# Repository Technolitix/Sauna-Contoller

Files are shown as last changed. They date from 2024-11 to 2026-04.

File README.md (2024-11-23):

# Sauna Controller

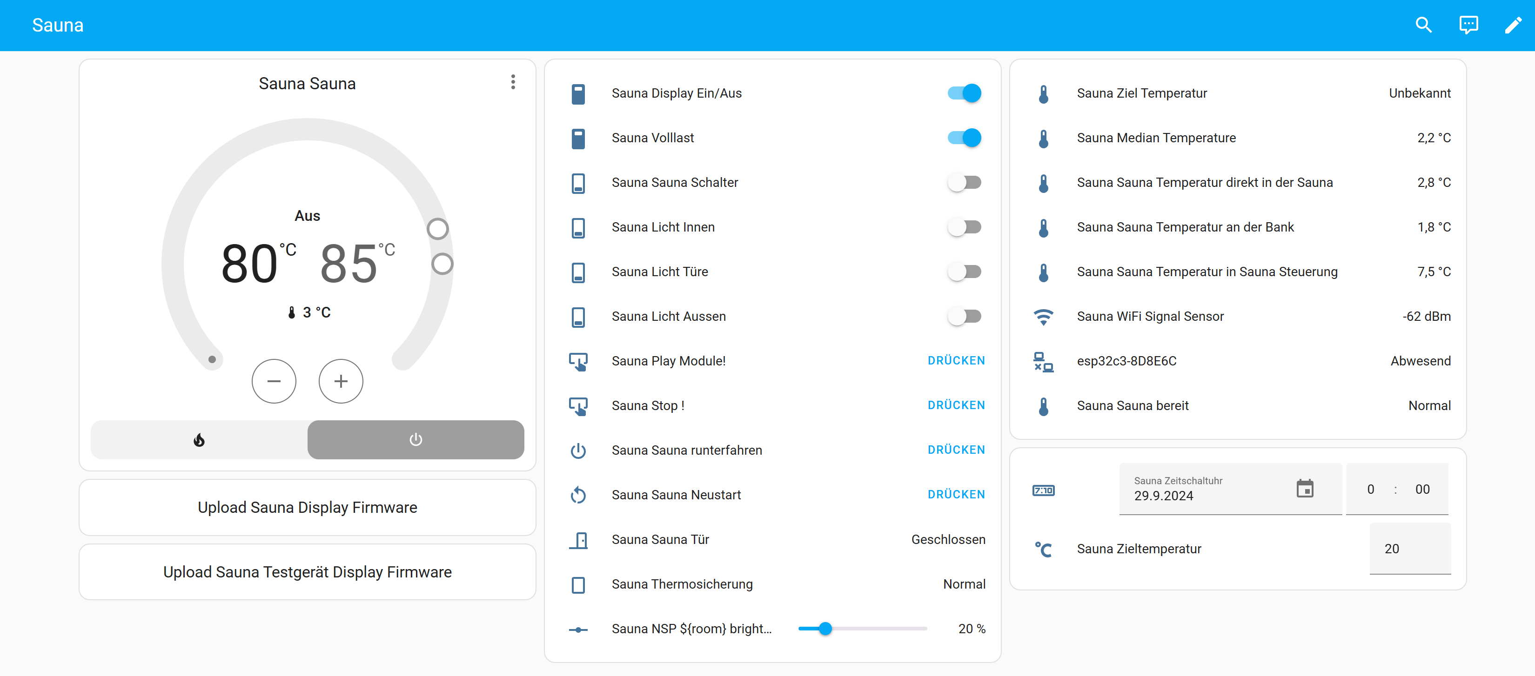
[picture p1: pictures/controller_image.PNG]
Sauna Controller


A project for controlling a sauna using sensors and actuators. This application allows precise management of temperature, humidity, and other parameters to ensure an optimal sauna experience.

---

## Features

- **Temperature Control**: Automatically adjusts the temperature based on predefined settings.
- **Humidity Management**: Integrates humidity sensors for maintaining the perfect sauna environment.
- **Scheduling**: Enables the sauna to operate at predefined times.
- **Fallback Mode**: Ensures stable operation even during connectivity issues.

---

## Configuration Overview

The main configuration file is `sauna1.yaml`. It contains all the necessary settings for operating the sauna controller. Sensitive data such as passwords and API keys are managed through references (`!secret`) in a separate file, such as `secrets.yaml`.

Example of a reference in the YAML file:
```yaml
wifi:
  ssid: !secret wifi_ssid_sauna
  password: !secret wifi_password_sauna
```

### Note
The `secrets.yaml` file is not included in this repository. It should contain sensitive data and remain private.

---

## Directory Structure

- **`config/`**: Contains main configuration files like `sauna1.yaml`.
- **`pictures/`**: Contains images for documentation and illustration.
- **`scripts/`**: Scripts supporting sauna control.
- **`logs/`**: Log files for debugging and tracking.

---

## Installation and Usage

### Prerequisites

- A device capable of managing the controller (e.g., Raspberry Pi, ESP32).
- Sensors and actuators compatible with the sauna setup.

### Steps

1. **Clone the repository**:
   ```bash
   git clone https://github.com/Technolitix/Sauna-Controller.git
   ```
2. **Adjust the configuration file**:
   Edit `sauna1.yaml` to suit your sauna's specific requirements.
3. **Configure secrets**:
   Create a `secrets.yaml` file and add sensitive data:
   ```yaml
   wifi_ssid_sauna: "YourWiFiName"
   wifi_password_sauna: "YourWiFiPassword"
   ```
4. **Deploy and start**:
   Upload the configuration to your device and start the controller.

---

## Security

- The `secrets.yaml` file should never be included in the repository.
- Always ensure sensitive data is stored externally and securely.

---

## Contact

If you have any questions or issues, feel free to open an [Issue](https://github.com/Technolitix/Sauna-Controller/issues).

---

## License

This project is licensed under the [MIT License](LICENSE).

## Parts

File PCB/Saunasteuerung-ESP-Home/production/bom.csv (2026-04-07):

Designator | Footprint | Quantity | Value | LCSC Part #
A1 | ESP32-S3-ETH | 1 | ESP32-S3-ETH
C1 | CP_Elec_6.3x3.9 | 1 | 220uF
C3 | 0603 | 1 | 1uF
D1, D10, D4, D6, D8 | D_SOD-123 | 5 | 1N4148W
D11, D12, D13, D14, D15, D2, D3, D5, D7, D9 | 0603 | 10 | LED
IC1 | SO08-SKINNYPADS | 1 | WS2811
J1, J2, J3 | HB9500M956P | 3 | HB9500M-9.5-6P
J4 | JST_XH_B8B-XH-A_1x08_P2.50mm_Vertical | 1 | Frontpanel I/O
J6 | JST_XH_B5B-XH-A_1x05_P2.50mm_Vertical | 1 | Frontpanel I2C
J7 | JST_XH_B3B-XH-A_1x03_P2.50mm_Vertical | 1 | WS2812
J8 | 696106003002_696106003002 | 1 | 696106003002
K1, K2, K3 | Relay_SPDT_RAYEX-L90 | 3 | RAYEX-L90
K4, K5 | Relay_SPDT_Omron_G2RL-1-E | 2 | G2RL-1-E
LS1 | CEM-1205C_CUI_CEM-1205C | 1 | CEM-1205C
PS1 | HLK-10M05_CONV_HLK-10M05 | 1 | HLK-10M05
Q1, Q2, Q3, Q5, Q6 | SOT-23 | 5 | S8550
Q10 | SOT-23 | 1 | 2N7002
Q11, Q12, Q8 | TO-252-2 | 3 | NTD5867NL
Q4, Q7, Q9 | SOT-323_SC-70 | 3 | BSS214NW
R1, R10, R12, R16, R19, R20, R23, R25, R27, R28, R30, R31, R33, R35, R37, R4, R6, R8 | 0603 | 18 | 1k
R11, R17, R2, R24, R26, R29, R32, R34, R36, R38, R39, R40, R7 | 0603 | 13 | 10k
R13, R14, R3, R5, R9 | 0603 | 5 | 2.2k
R15 | 0603 | 1 | 4.7k
R18 | 0603 | 1 | 2k74
R21, R41, R42 | 0603 | 3 | 33
R22 | 0603 | 1 | 100
RV1 | RV_Disc_D7mm_W3.4mm_P5mm | 1 | 10D561K
U1, U10, U2, U3, U9 | SOP-4_4.4x2.6mm_P1.27mm | 5 | FODM217A
U5 | TO-92L | 1 | DS18B20
X1 | 250-212_P-250-212 | 1 | Sensors
X2 | 250-212_P-250-212 | 1 | LED's

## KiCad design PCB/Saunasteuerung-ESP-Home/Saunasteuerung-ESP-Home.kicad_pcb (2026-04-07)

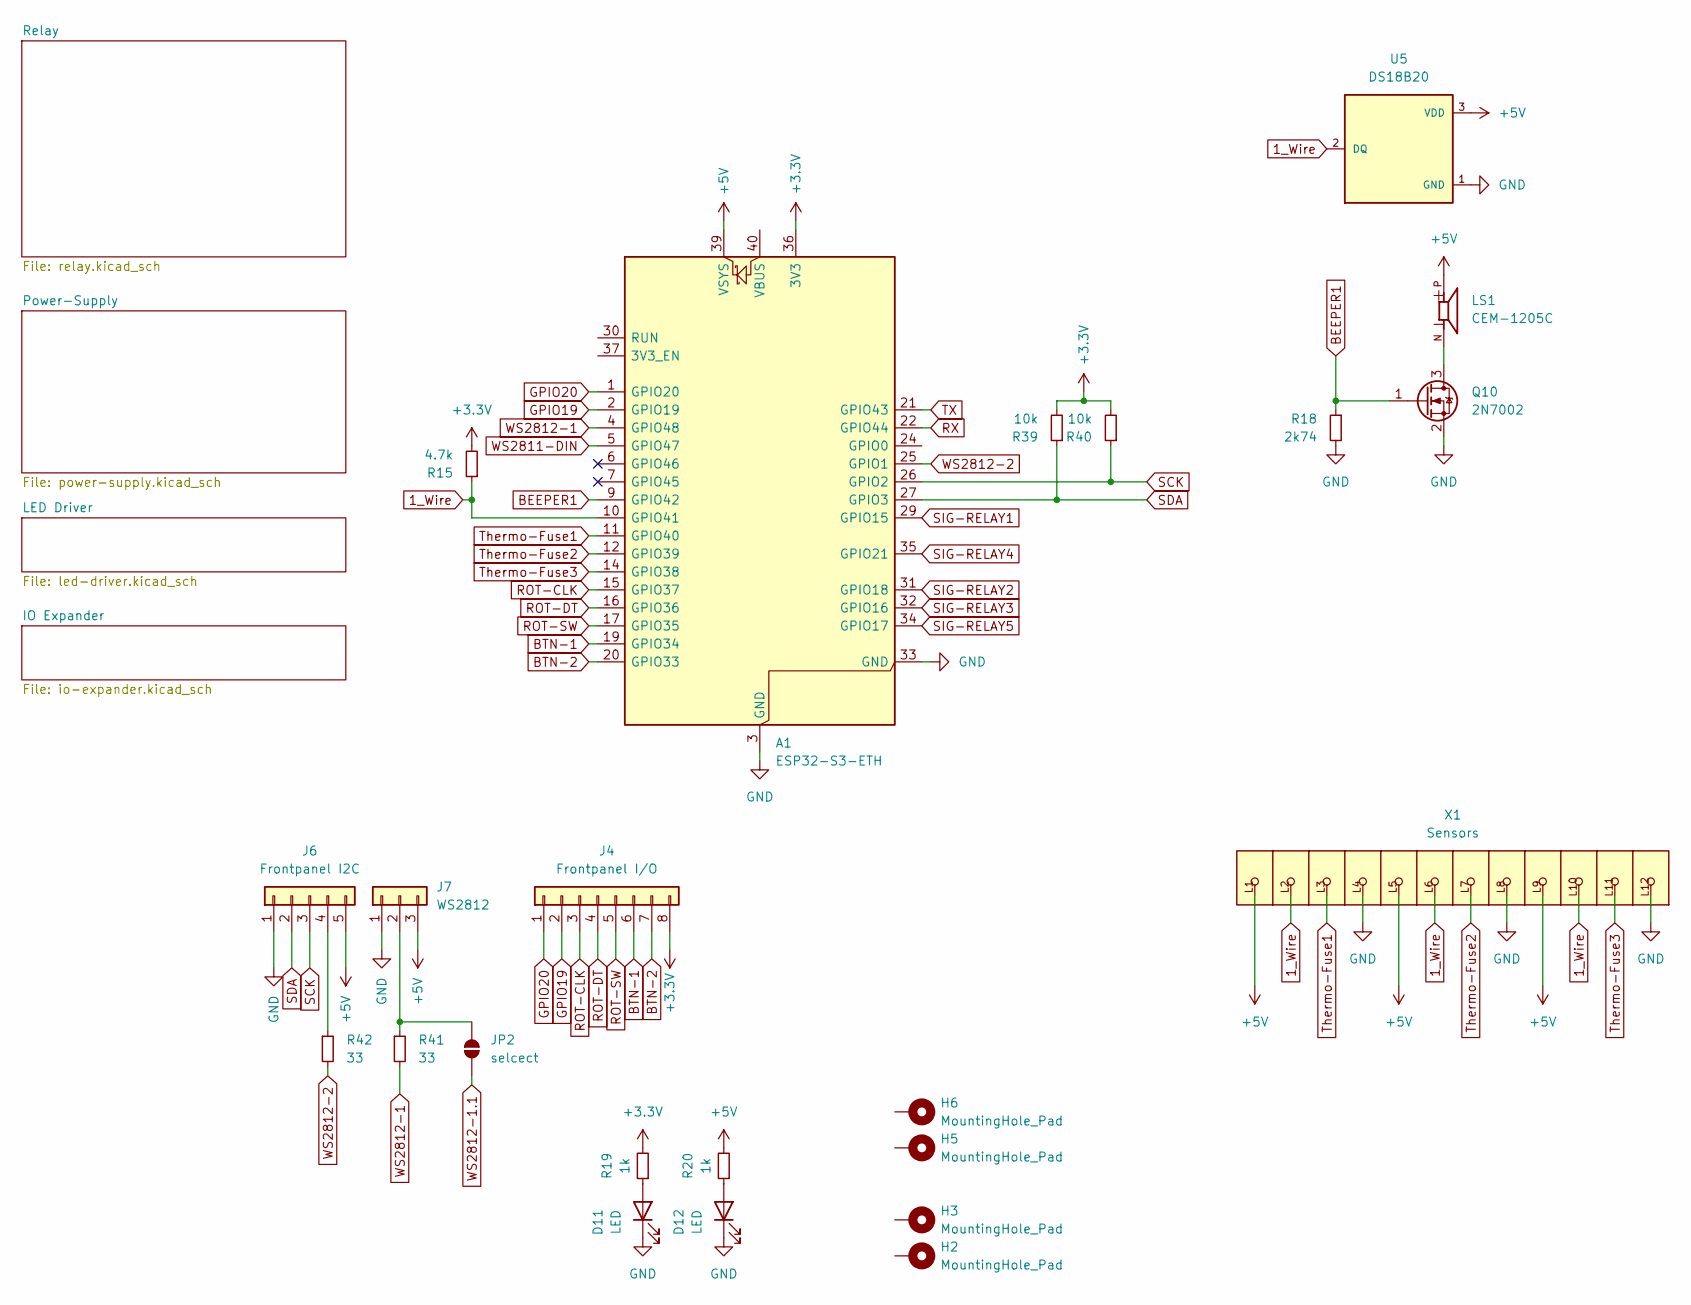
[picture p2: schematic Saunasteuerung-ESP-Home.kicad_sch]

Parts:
A1: ESP32-S3-ETH
D11, D12: LED; LED_0603_1608Metric
H2, H3, H5, H6: MountingHole_Pad; MountingHole_3.2mm_M3_DIN965_Pad_TopBottom
J4: Frontpanel I/O; JST_XH_B8B-XH-A_1x08_P2.50mm_Vertical
J6: Frontpanel I2C; JST_XH_B5B-XH-A_1x05_P2.50mm_Vertical
J7: WS2812; JST_XH_B3B-XH-A_1x03_P2.50mm_Vertical
JP2: selcect; SolderJumper-2_P1.3mm_Open_TrianglePad1.0x1.5mm
LS1: CEM-1205C; CEM-1205C_CUI_CEM-1205C
Q10: 2N7002; SOT-23
R15: 4.7k; R_0603_1608Metric
R18: 2k74; R_0603_1608Metric
R19, R20: 1k; R_0603_1608Metric
R39, R40: 10k; R_0603_1608Metric
R41, R42: 33; R_0603_1608Metric
U5: DS18B20; TO-92L; PARTREV 5
X1: Sensors; 250-212_P-250-212

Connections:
1_Wire: A1.10 (GPIO41), R15.1, U5.2 (DQ), X1.L2, X1.L6, X1.L10
+3.3V: A1.36 (3V3), J4.8, R15.2, R19.2, R39.2, R40.2
+5V: A1.39 (VSYS), J6.5, J7.3, LS1.P, R20.2, U5.3 (VDD), X1.L1, X1.L5, X1.L9; also elsewhere on the board
BEEPER1: A1.9 (GPIO42), Q10.1 (G), R18.1
BTN-1: A1.19 (GPIO34), J4.6
BTN-2: A1.20 (GPIO33), J4.7
GND: A1.3 (GND), A1.8 (GND), A1.13 (GND), A1.18 (GND), A1.23 (GND), A1.28 (GND), A1.33 (GND), A1.38 (GND), D11.1 (K), D12.1 (K), J6.1, J7.1, Q10.2 (S), R18.2, U5.1 (GND), X1.L4, X1.L8, X1.L12; also elsewhere on the board
GPIO19: A1.2 (GPIO19), J4.2
GPIO20: A1.1 (GPIO20), J4.1
unnamed: D11.2 (A), R19.1
unnamed: D12.2 (A), R20.1
unnamed: J6.4, R42.1
unnamed: J7.2, JP2.2 (B), R41.1
unnamed: LS1.N, Q10.3 (D)
ROT-CLK: A1.15 (GPIO37), J4.3
ROT-DT: A1.16 (GPIO36), J4.4
ROT-SW: A1.17 (GPIO35), J4.5
RX: A1.22 (GPIO44)
SCK: A1.26 (GPIO2), J6.3, R40.1
SDA: A1.27 (GPIO3), J6.2, R39.1
SIG-RELAY1: A1.29 (GPIO15); also elsewhere on the board
SIG-RELAY2: A1.31 (GPIO18); also elsewhere on the board
SIG-RELAY3: A1.32 (GPIO16); also elsewhere on the board
SIG-RELAY4: A1.35 (GPIO21); also elsewhere on the board
SIG-RELAY5: A1.34 (GPIO17); also elsewhere on the board
TX: A1.21 (GPIO43)
Thermo-Fuse1: A1.11 (GPIO40), X1.L3
Thermo-Fuse2: A1.12 (GPIO39), X1.L7
Thermo-Fuse3: A1.14 (GPIO38), X1.L11
WS2811-DIN: A1.5 (GPIO47); also elsewhere on the board
WS2812-1: A1.4 (GPIO48), R41.2
WS2812-1.1: JP2.1 (A); also elsewhere on the board
WS2812-2: A1.25 (GPIO1), R42.2

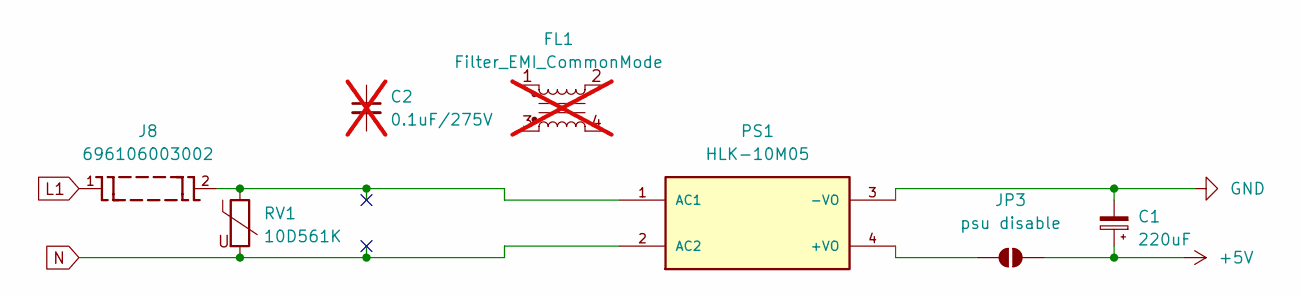
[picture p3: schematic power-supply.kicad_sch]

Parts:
C1: 220uF; CP_Elec_6.3x3.9
C2: 0.1uF/275V; not fitted
FL1: Filter_EMI_CommonMode; L_CommonMode_PulseElectronics_PH9455x105NL_1; not fitted
J8: 696106003002; 696106003002_696106003002; PART-NUMBER 696106003002
JP3: psu disable; SolderJumper-2_P1.3mm_Bridged_Pad1.0x1.5mm
PS1: HLK-10M05; HLK-10M05_CONV_HLK-10M05; PARTREV V1.8
RV1: 10D561K; RV_Disc_D7mm_W3.4mm_P5mm

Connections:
+5V: C1.1, JP3.2 (B); also elsewhere on the board
GND: C1.2, PS1.3 (-VO); also elsewhere on the board
L1: J8.1; also elsewhere on the board
N: PS1.2 (AC2), RV1.2; also elsewhere on the board
unnamed: JP3.1 (A), PS1.4 (+VO)

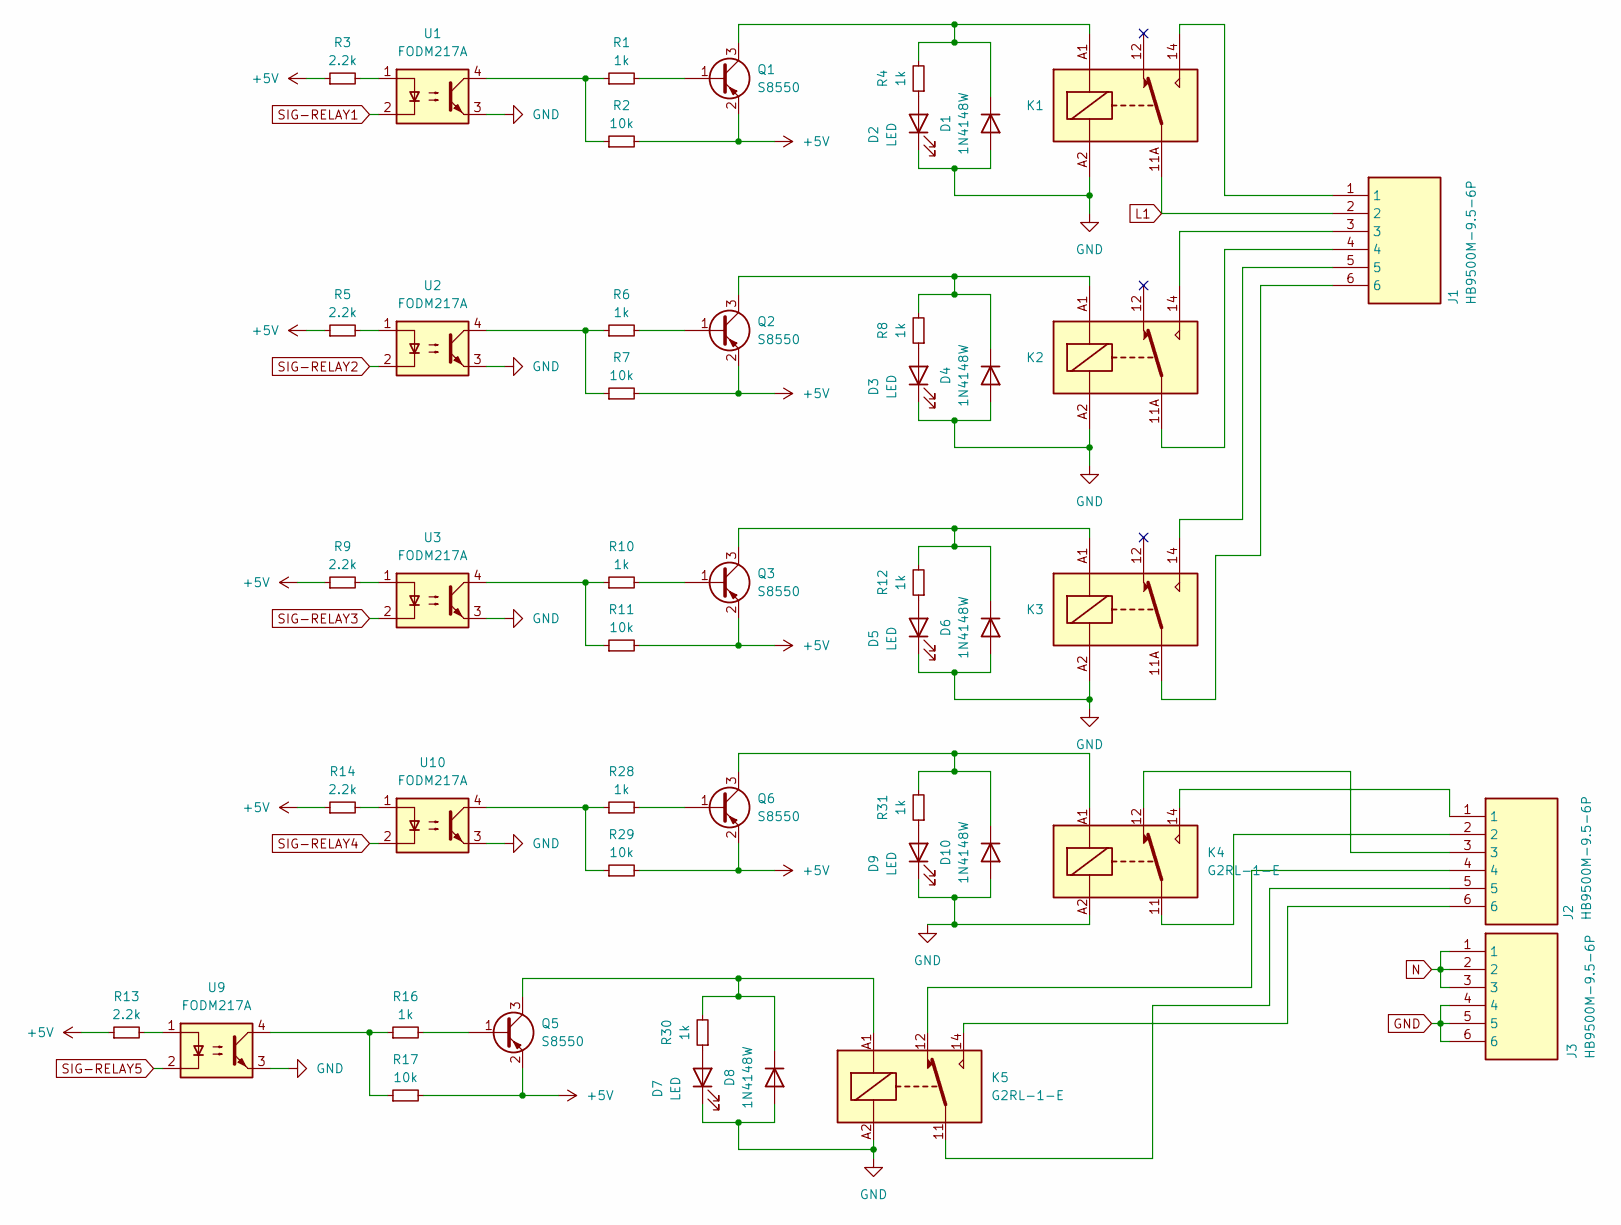
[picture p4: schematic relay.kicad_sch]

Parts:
D1, D4, D6, D8, D10: 1N4148W; D_SOD-123
D2, D3, D5, D7, D9: LED; LED_0603_1608Metric
J1, J2, J3: HB9500M-9.5-6P; HB9500M956P; Manufacturer_Part_Number HB9500M-9.5-6P
K1, K2, K3: RAYEX-L90; Relay_SPDT_RAYEX-L90
K4, K5: G2RL-1-E; Relay_SPDT_Omron_G2RL-1-E
Q1, Q2, Q3, Q5, Q6: S8550; SOT-23
R1, R4, R6, R8, R10, R12, R16, R28, R30, R31: 1k; R_0603_1608Metric
R2, R7, R11, R17, R29: 10k; R_0603_1608Metric
R3, R5, R9, R13, R14: 2.2k; R_0603_1608Metric
U1, U2, U3, U9, U10: FODM217A; SOP-4_4.4x2.6mm_P1.27mm

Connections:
+5V: Q1.2 (E), Q2.2 (E), Q3.2 (E), Q5.2 (E), Q6.2 (E), R2.2, R3.1, R5.1, R7.2, R9.1, R11.2, R13.1, R14.1, R17.2, R29.2; also elsewhere on the board
GND: D1.2 (A), D2.1 (K), D3.1 (K), D4.2 (A), D5.1 (K), D6.2 (A), D7.1 (K), D8.2 (A), D9.1 (K), D10.2 (A), J3.4, J3.5, J3.6, K1.A2, K2.A2, K3.A2, K4.A2, K5.A2, U1.3, U2.3, U3.3, U9.3, U10.3; also elsewhere on the board
L1: J1.2, K1.11A, K1.11B; also elsewhere on the board
N: J3.1, J3.2, J3.3; also elsewhere on the board
unnamed: D1.1 (K), K1.A1, Q1.3 (C), R4.2
unnamed: D2.2 (A), R4.1
unnamed: D3.2 (A), R8.1
unnamed: D4.1 (K), K2.A1, Q2.3 (C), R8.2
unnamed: D5.2 (A), R12.1
unnamed: D6.1 (K), K3.A1, Q3.3 (C), R12.2
unnamed: D7.2 (A), R30.1
unnamed: D8.1 (K), K5.A1, Q5.3 (C), R30.2
unnamed: D9.2 (A), R31.1
unnamed: D10.1 (K), K4.A1, Q6.3 (C), R31.2
unnamed: J1.1, K1.14
unnamed: J1.3, K2.14
unnamed: J1.4, K2.11A, K2.11B
unnamed: J1.5, K3.14
unnamed: J1.6, K3.11A, K3.11B
unnamed: J2.1, K4.14
unnamed: J2.2, K4.11
unnamed: J2.3, K4.12
unnamed: J2.4, K5.12
unnamed: J2.5, K5.11
unnamed: J2.6, K5.14
unnamed: Q1.1 (B), R1.2
unnamed: Q2.1 (B), R6.2
unnamed: Q3.1 (B), R10.2
unnamed: Q5.1 (B), R16.2
unnamed: Q6.1 (B), R28.2
unnamed: R1.1, R2.1, U1.4
unnamed: R3.2, U1.1
unnamed: R5.2, U2.1
unnamed: R6.1, R7.1, U2.4
unnamed: R9.2, U3.1
unnamed: R10.1, R11.1, U3.4
unnamed: R13.2, U9.1
unnamed: R14.2, U10.1
unnamed: R16.1, R17.1, U9.4
unnamed: R28.1, R29.1, U10.4
SIG-RELAY1: U1.2; also elsewhere on the board
SIG-RELAY2: U2.2; also elsewhere on the board
SIG-RELAY3: U3.2; also elsewhere on the board
SIG-RELAY4: U10.2; also elsewhere on the board
SIG-RELAY5: U9.2; also elsewhere on the board

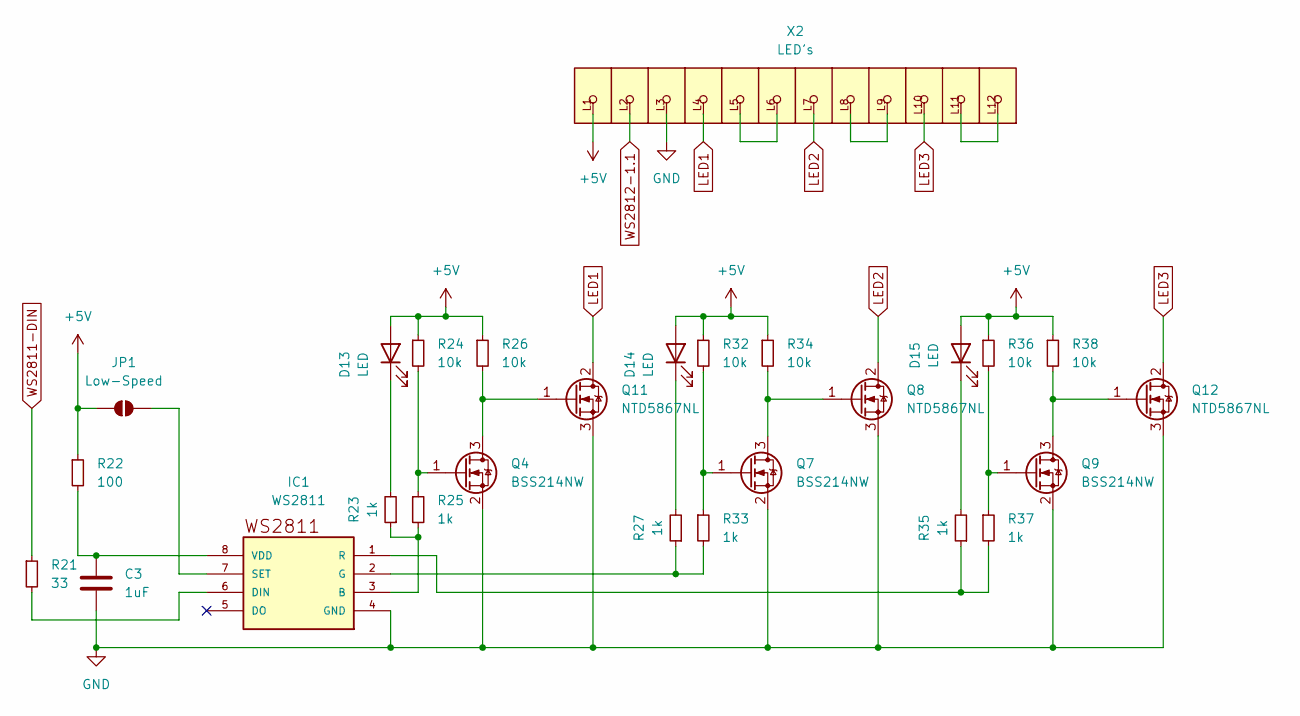
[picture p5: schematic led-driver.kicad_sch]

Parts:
C3: 1uF; C_0603_1608Metric
D13, D14, D15: LED; LED_0603_1608Metric
IC1: WS2811; SO08-SKINNYPADS
JP1: Low-Speed; SolderJumper-2_P1.3mm_Open_TrianglePad1.0x1.5mm
Q4, Q7, Q9: BSS214NW; SOT-323_SC-70
Q8, Q11, Q12: NTD5867NL; TO-252-2
R21: 33; R_0603_1608Metric
R22: 100; R_0603_1608Metric
R23, R25, R27, R33, R35, R37: 1k; R_0603_1608Metric
R24, R26, R32, R34, R36, R38: 10k; R_0603_1608Metric
X2: LED's; 250-212_P-250-212

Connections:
+5V: D13.2 (A), D14.2 (A), D15.2 (A), JP1.2 (B), R22.1, R24.1, R26.1, R32.1, R34.1, R36.1, R38.1, X2.L1; also elsewhere on the board
GND: C3.2, IC1.4 (GND), Q4.2 (S), Q7.2 (S), Q8.3 (S), Q9.2 (S), Q11.3 (S), Q12.3 (S), X2.L3; also elsewhere on the board
LED1: Q11.2 (D), X2.L4
LED2: Q8.2 (D), X2.L7
LED3: Q12.2 (D), X2.L10
unnamed: D13.1 (K), R23.2
unnamed: D14.1 (K), R27.2
unnamed: D15.1 (K), R35.2
unnamed: IC1.3 (B), R23.1, R25.2
unnamed: IC1.6 (DIN), R21.2
unnamed: IC1.2 (G), R27.1, R33.2
unnamed: IC1.1 (R), R35.1, R37.2
unnamed: IC1.7 (SET), JP1.1 (A)
unnamed: C3.1, IC1.8 (VDD), R22.2
unnamed: Q4.1 (G), R24.2, R25.1
unnamed: Q7.3 (D), Q8.1 (G), R34.2
unnamed: Q7.1 (G), R32.2, R33.1
unnamed: Q9.1 (G), R36.2, R37.1
unnamed: Q4.3 (D), Q11.1 (G), R26.2
unnamed: Q9.3 (D), Q12.1 (G), R38.2
unnamed: X2.L5, X2.L6
unnamed: X2.L8, X2.L9
unnamed: X2.L11, X2.L12
WS2811-DIN: R21.1; also elsewhere on the board
WS2812-1.1: X2.L2; also elsewhere on the board

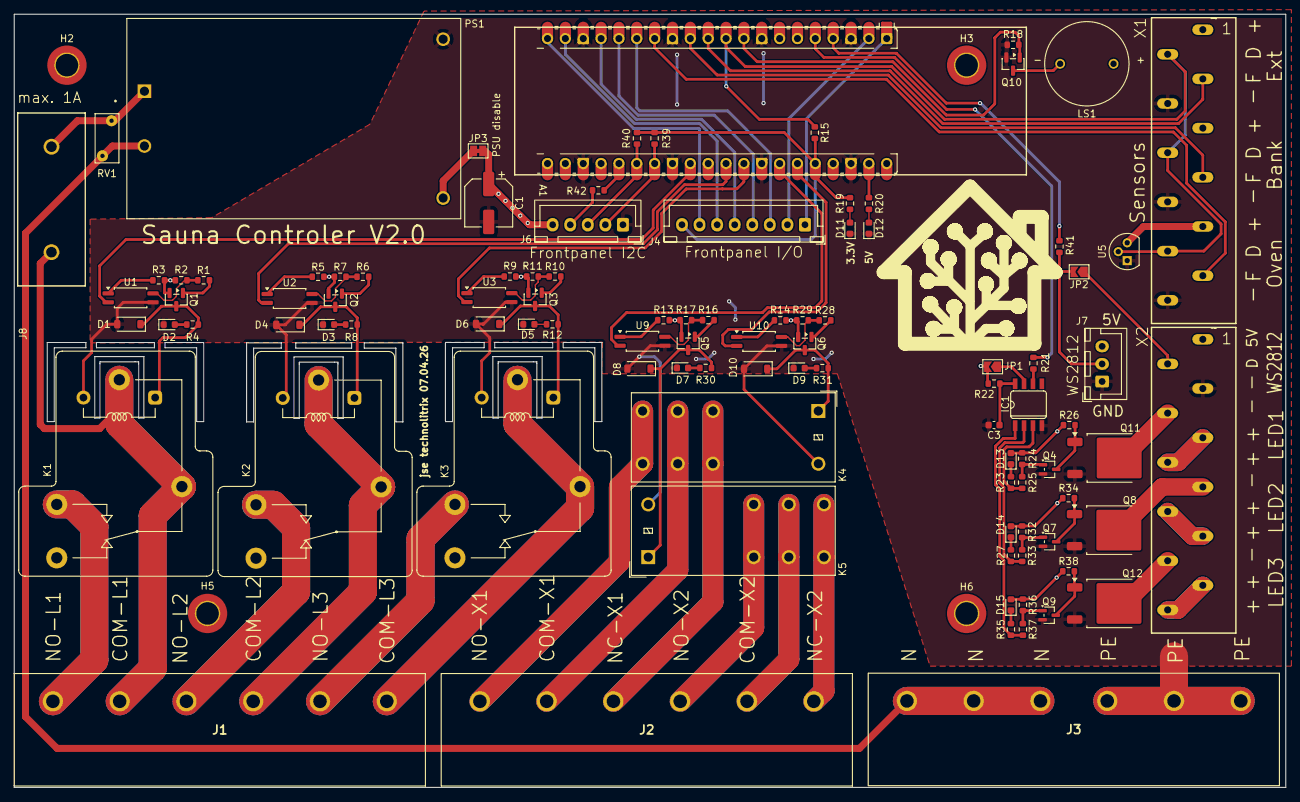
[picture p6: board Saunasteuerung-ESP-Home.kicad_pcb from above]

Board: 2 copper layers, 180.9 x 110.0 mm, 103 parts (0 on the bottom side), 91 nets.

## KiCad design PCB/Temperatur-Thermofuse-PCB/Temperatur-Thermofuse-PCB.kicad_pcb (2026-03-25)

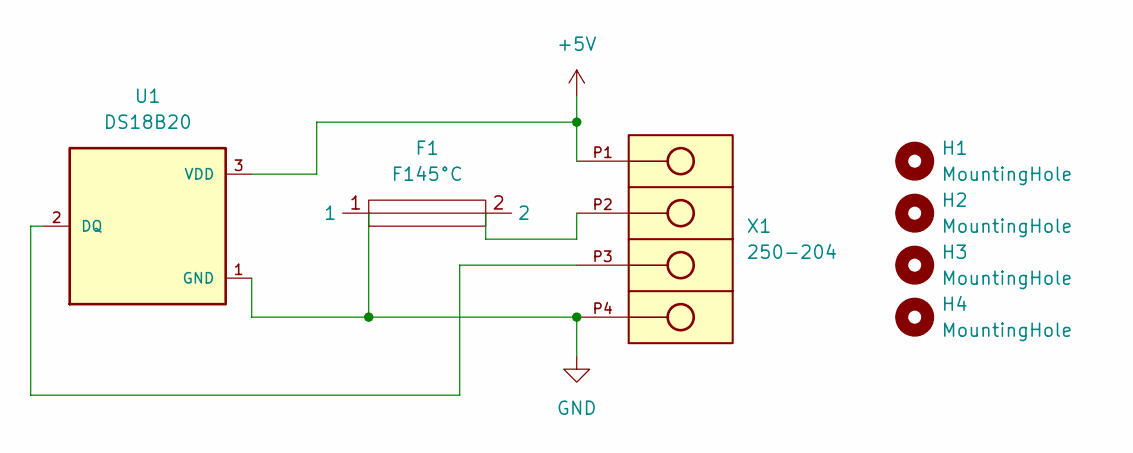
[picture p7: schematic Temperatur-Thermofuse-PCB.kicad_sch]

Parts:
F1: F145°C; THERMALFUSE
H1, H2, H3, H4: MountingHole; MountingHole_3.2mm_M3
U1: DS18B20; DS18B20_TO-92-TO92127P495H2044-3; PARTREV 5
X1: 250-204; 250-204_WAGO_250-204

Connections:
+5V: U1.3 (VDD), X1.P1
GND: F1.1, U1.1 (GND), X1.P4
unnamed: F1.2, X1.P2
unnamed: U1.2 (DQ), X1.P3

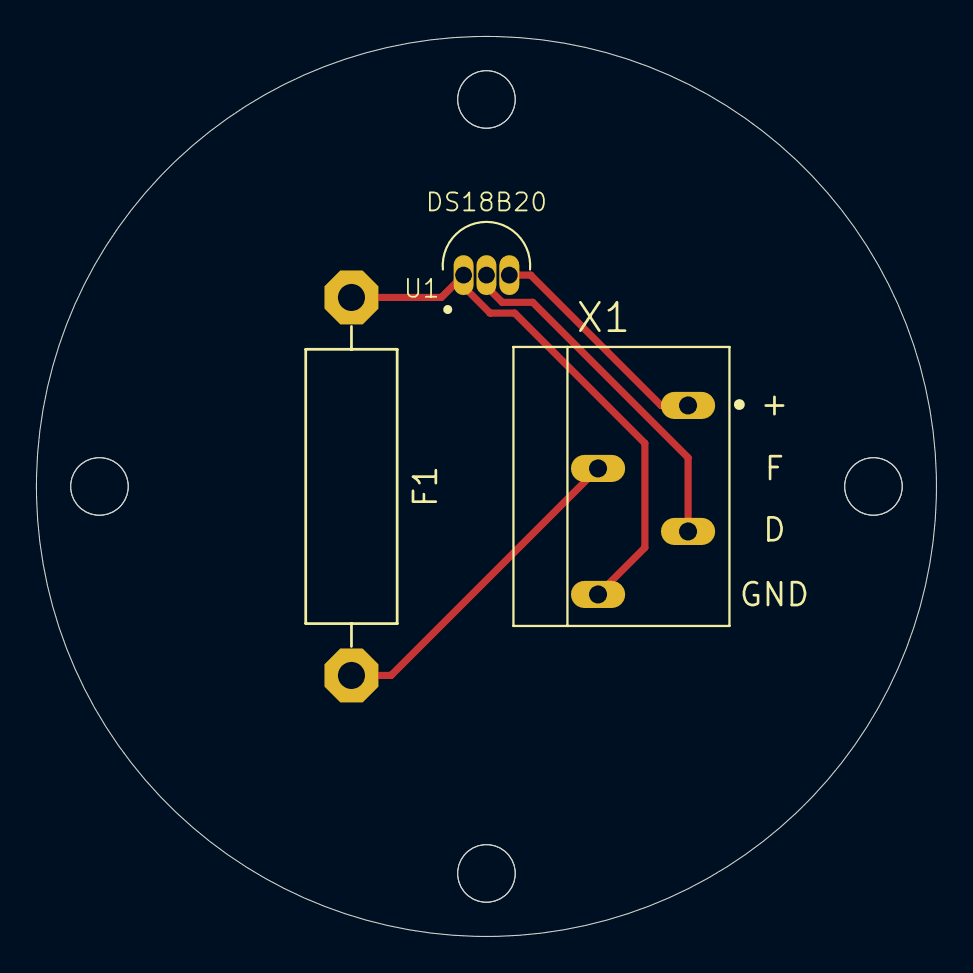
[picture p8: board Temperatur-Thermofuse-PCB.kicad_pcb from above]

Board: 2 copper layers, 50.0 x 50.0 mm, 7 parts (0 on the bottom side), 4 nets.

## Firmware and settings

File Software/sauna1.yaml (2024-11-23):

substitutions:
  #statics
  standard_target_temp_high: "85°C"
  standard_target_temp_low: "80°C"
  max_power_generic: "1.0"
  #power of the sauna oven (kw dividet 100)
  power_of_sauna_oven: "0.108"
  uart_baud_rate: "115200"
  oven_sensor_addr: "0x4a00000032a8ad28"
  bank_sensor_addr: "0xc3000000329d3f28"
  electric_box_sensor_addr: "0xea000000306fe528"

  #I/O-Pins
  rx_pin: "GPIO1"
  tx_pin: "GPIO20"
  sda_pin: "GPIO9"  
  scl_pin: "GPIO10"
  dallas_pin: "GPIO6"
  mcp23017_reset_pin: "GPIO8"
  sclk_pin: "GPIO2"
  miso_pin: "GPIO3"
  mosi_pin: "GPIO4"
  sccn_pin: "GPIO7"
  relay_1: "0"
  relay_2: "1"
  relay_3: "2"
  relay_4: "3"
  relay_5: "4"
  led_1: "8"
  led_2: "7"
  led_3: "6"
  led_4: "5"
  ws2812_pin: "GPIO0"
  thermal_fuse1_pin: "10"
  door_sensor1_pin: "11"
  thermal_fuse2_pin: "12"
  beeper1_pin: "GPIO21"


esphome:
  name: sauna1
  friendly_name: Sauna
  platformio_options:
    board_build.flash_mode: dio
  on_boot:
    priority: -100
    then:
      - output.turn_off: heating_element_1
      - output.turn_off: heating_element_2
      - output.turn_off: heating_element_3
      - climate.control:
          id: sauna_climate
          mode: 'OFF'
          target_temperature_high: ${standard_target_temp_high}
          target_temperature_low: ${standard_target_temp_low}
      - globals.set:
          id: loading_screen
          value: 'false'


esp32:
  board: esp32-c3-devkitm-1
  framework:
    type: arduino

# Enable logging
logger: 
  baud_rate: 0

# Enable Home Assistant API
api:
  encryption:
    key: !secret api_key_sauna
  services:
    - service: upload_tft
      then:
        - lambda: "id(nextion1)->upload_tft();"

ota:
  - platform: esphome
    password: !secret ota_key_sauna

wifi:
  ssid: !secret wifi_ssid_sauna
  password: !secret wifi_password_sauna

# Example configuration entry for SPI chips
#ethernet:
#  type: W5500
#  clk_pin: GPIO2
#  mosi_pin: GPIO4
#  miso_pin: GPIO3
#  cs_pin: GPIO7
#interrupt_pin: "16"
#reset_pin: "15"

  # Enable fallback hotspot (captive portal) in case wifi connection fails
  ap:
    ssid: "Sauna1 Fallback Hotspot"
    password: !secret fallback_hotspot_pw_sauna

uart:
  id: nextion1_uart
  rx_pin: ${rx_pin}
  tx_pin: ${tx_pin}
  baud_rate: ${uart_baud_rate}

i2c:
  sda: ${sda_pin}
  scl: ${scl_pin}
  scan: True

mcp23017:
  - id: 'mcp23017_hub'
    address: 0x27

globals:
  - id: count_global_int
    type: int
    restore_value: false
    initial_value: '0'

  - id: count_global_door_int
    type: int
    restore_value: false
    initial_value: '0'

  - id: count_global_set_val
    type: int
    restore_value: true
    initial_value: '90'

  - id: count_global_door_set_val
    type: int
    restore_value: true
    initial_value: '99999999'

  - id: current_element
    type: int
    restore_value: no
    initial_value: '0'

  - id: full_power_mode
    type: int
    restore_value: no
    initial_value: '1'

  - id: default_target_temperature
    type: int
    restore_value: no
    initial_value: '0'

  - id: sauna_on_off
    type: bool
    restore_value: no
    initial_value: '0'

#Sauna Lichter
  - id: sauna_light
    type: bool
    restore_value: no
    initial_value: '0'
  - id: outdoor_light
    type: bool
    restore_value: no
    initial_value: '0'

  - id: sauna_light_led1
    type: bool
    restore_value: no
    initial_value: '0'
  - id: sauna_light_led2
    type: bool
    restore_value: no
    initial_value: '0'
  - id: sauna_light_led3
    type: bool
    restore_value: no
    initial_value: '0'
  - id: sauna_light_led4
    type: bool
    restore_value: no
    initial_value: '0'

  - id: display_wake
    type: bool
    restore_value: no
    initial_value: '0'
  - id: loading_screen
    type: bool
    restore_value: no
    initial_value: '0'

  - id: thermal_fuse_state
    type: bool
    restore_value: no
    initial_value: '0'

  - id: set_temp_standart_value
    type: int
    restore_value: no
    initial_value: '0'


# Change heat elements 
interval:
  - interval: 5s
    then:
      - lambda: |-
          if (!id(full_power_mode)) {
          id(current_element) = (id(current_element) + 1) % 3;
          //ESP_LOGD("main", "Current element: %d", id(current_element));
          }

rtttl:
  output: rtttl_out

output:

  - platform: ledc
    pin: ${beeper1_pin} 
    id: rtttl_out
    inverted: True
    frequency: 10000 Hz

  - platform: gpio
    pin: 
      mcp23xxx: mcp23017_hub
      number: ${relay_1} 
      mode: 
        output: true
      inverted: true
    id: heating_element_1

  - platform: gpio
    pin: 
      mcp23xxx: mcp23017_hub 
      number: ${relay_2} 
      mode: 
        output: true
      inverted: true
    id: heating_element_2

  - platform: gpio
    pin: 
      mcp23xxx: mcp23017_hub 
      number: ${relay_3}
      mode: 
        output: true
      inverted: true
    id: heating_element_3
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

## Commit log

2024-11-23 Inital Commit
    [Saunasteuerung-ESP-Home.kicad_pcb, Saunasteuerung-ESP-Home.kicad_sch, Temperatur-Thermofuse-PCB.kicad_pcb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]
2025-03-09 Added AD5593
    [Saunasteuerung-ESP-Home.kicad_sch, io-expander.kicad_sch, led-driver.kicad_sch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]
2026-03-25 removed old pcb files
    [Saunasteuerung-ESP-Home.kicad_pcb, Saunasteuerung-ESP-Home.kicad_sch, Temperatur-Thermofuse-PCB.kicad_pcb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]
2026-04-06 V2.0 push
    [Saunasteuerung-ESP-Home.kicad_pcb, Saunasteuerung-ESP-Home.kicad_sch, bom.csv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]
